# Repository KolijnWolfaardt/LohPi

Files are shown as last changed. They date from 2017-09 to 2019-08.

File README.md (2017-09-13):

# LohPi
A Lora Hat for Raspberry Pi

The PCB uses a [Semtech SX1301](http://www.semtech.com/images/datasheet/sx1301.pdf) to implement a full gateway for a LoRaWan connection. It is intended to plug into a Raspberri Pi 3 which manages the packet forwarding. 

# RF Frontend
The RF frontend is responsible for mixing down the signal, sampling it as IQ samples, and sending it to the SX1301 IC. For this two [SX1257](http://www.semtech.com/images/datasheet/sx1257.pdf) ICs are used. The schematic of the RF frontend is adapted from [Microchip's Documentation](http://ww1.microchip.com/downloads/en/DeviceDoc/40001827A.pdf).

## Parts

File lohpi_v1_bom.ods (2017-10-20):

Reference | Quantity | Value | Footprint | Datasheet | Voltage | I | Manufacturer | Manufacturer Code | Manufacturer Link | Supplier 1 | Supplier 1 Code | Supplier 1 Link | Supplier 2 | Supplier 2 Code | Supplier 2 Link
C1 C8 | 2 | 10uF | Capacitors_SMD:C_0603 |  | 25v |  | Taiuo Yuden | TMK107BBJ106MA-T |  | Mouser | 963-TMK107BBJ106MA-T | link (http://www.mouser.co.za/ProductDetail/Taiyo-Yuden/TMK107BBJ106MA-T/)
C10 C11 C12 C2 C37 C5 C9 | 7 | 4.7uF | Capacitors_SMD:C_0603 |  |  |  | Taiuo Yuden | JMK107BB7475KA-T |  | Mouser | 963-JMK107BB7475KA-T | link (http://www.mouser.co.za/ProductDetail/Taiyo-Yuden/JMK107BB7475KA-T/)
C13 C43 C44 C6 C78 C83 | 6 | 10nF | Capacitors_SMD:C_0402_NoSilk |  |  |  | Taiuo Yuden | TMK105B7103KVHF |  | Mouser | 963-TMK105B7103KVHF | link (http://www.mouser.co.za/ProductDetail/Taiyo-Yuden/TMK105B7103KVHF/)
C14 C15 C16 C17 C24 C30 C7 C84 C85 C86 C87 C89 C90 C91 | 14 | 1.0uF | Capacitors_SMD:C_0603 |  |  |  | Taiuo Yuden | GMK107AB7105MAHT |  | Mouser | 963-GMK107AB7105MAHT | link (http://www.mouser.co.za/ProductDetail/Taiyo-Yuden/GMK107AB7105MAHT/)
C18 C19 C20 C21 C22 C23 C53 C54 C56 C58 C61 C62 C65 C68 C69 C70 C71 C73 C75 C76 C77 | 21 | 56pF | Capacitors_SMD:C_0402_NoSilk |  |  |  | Vishay | VJ0402D560JXAAJ |  | Mouser | 77-VJ0402D560JXAAJ | link (http://www.mouser.co.za/search/ProductDetail.aspx?R=VJ0402D560JXAAJ)
 | 0 | 56pF | Capacitors_SMD:C_0402_NoSilk |  |  |  | Taiuo Yuden | UMK105CG560JV-F |  | Mouser | 963-UMK105CG560JV-F | link (http://www.mouser.co.za/ProductDetail/Taiyo-Yuden/UMK105CG560JV-F/)
C25 C26 C27 C28 C29 C3 C31 C32 C33 | 9 | 100nF | Capacitors_SMD:C_0603 |  |  |  | Taiuo Yuden | TMK107BJ104KA-T |  | Mouser | 963-TMK107BJ104KA-T | link (http://www.mouser.co.za/ProductDetail/Taiyo-Yuden/TMK107BJ104KA-T/)
C34 C35 C45 C47 C49 C50 | 6 | 1uF | Capacitors_SMD:C_0402_NoSilk |  |  |  | Taiuo Yuden | TMK105AC6105KV-F |  | Mouser | 963-TMK105AC6105KV-F | link (http://www.mouser.co.za/ProductDetail/Taiyo-Yuden/TMK105AC6105KV-F/)
C36 C39 C40 C41 C42 C46 C48 C63 C64 C82 C88 | 11 | 100nF | Capacitors_SMD:C_0402_NoSilk |  | 10v |  | Taiuo Yuden | LMK105B7104KV-F |  | Mouser | 963-LMK105B7104KV-F | link (http://www.mouser.co.za/ProductDetail/Taiyo-Yuden/LMK105B7104KV-F/)
C38 C4 C79 C80 | 4 | 1nF | Capacitors_SMD:C_0603 |  |  |  | Taiuo Yuden | HMK107B7102KA-T |  | Mouser | 963-HMK107B7102KA-T | link (http://www.mouser.co.za/ProductDetail/Taiyo-Yuden/HMK107B7102KA-T/)
C51 C52 C57 C60 C72 | 5 | DNP | Capacitors_SMD:C_0402_NoSilk
C55 C81 | 2 | 1.5pF | Capacitors_SMD:C_0402_NoSilk |  |  |  | Vishay | VJ0402D1R5BXCAJ |  | Mouser | 77-VJ0402D1R5BXCAJ | link (http://www.mouser.co.za/ProductDetail/Vishay-Vitramon/VJ0402D1R5BXCAJ/)
C59 C66 C67 | 3 | 2.2uF | Capacitors_SMD:C_0402_NoSilk |  |  |  | Taiuo Yuden | TMK105CBJ225MV-F |  | Mouser | 963-TMK105CBJ225MV-F | link (http://www.mouser.co.za/ProductDetail/Taiyo-Yuden/TMK105CBJ225MV-F/)
C74 | 1 | 5.6pF | Capacitors_SMD:C_0402_NoSilk |  |  |  | Vishay | VJ0402D5R6BXCAJ |  | Mouser | 77-VJ0402D5R6BXCAJ | link (http://www.mouser.co.za/ProductDetail/Vishay-Vitramon/VJ0402D5R6BXCAJ/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)
D1 D2 D3 D4 | 4 | LED | LEDs:LED_0603 |  |  |  | Broadcom | HSMR-C191-S0000 |  | Mouser | 630-HSMR-C191-S0000 | link (http://www.mouser.co.za/ProductDetail/Broadcom-Avago/HSMR-C191-S0000/)
J1 | 1 | CONN_01X02 | Pin_Headers:Pin_Header_Straight_1x02_Pitch2.54mm
J10 J11 J12 J13 | 4 | CONN_01X01 | rpi_mounting_hole:rpi_mounting_hole
J2 J3 J4 J5 J6 | 5 | CONN_01X01 | Pin_Headers:Pin_Header_Straight_1x01_Pitch2.54mm
J7 | 1 | UFL | hirose:u.fl | Datasheet (http://www.mouser.com/ds/2/238/conufl001-smd-1130574.pdf) |  |  | Linx Technologies | CONUFL001-SMD |  | Mouser | 712-CONUFL001-SMD | link (http://www.mouser.co.za/ProductDetail/Linx-Technologies/CONUFL001-SMD/)
J8 | 1 | raspberry_pi_3_header | Socket_Strips:Socket_Strip_Straight_2x20_Pitch2.54mm |  |  |  | Amphenol | 87606-310LF |  | Mouser | 649-87606-310LF | link (http://www.mouser.co.za/ProductDetail/Amphenol-FCI/87606-310LF/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)
J9 | 1 | CONN_01X02 | Connectors:SMA_THT_Jack_Straight |  |  |  | Linx Technologies | CONREVSMA002-G |  | Mouser | 712-CONREVSMA002-G | link (http://www.mouser.co.za/ProductDetail/Linx-Technologies/CONREVSMA002-G/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)
L1 | 1 | 3.3uH |  |  |  | 1A | muRata | 84332C |  | Mouser | 580-84332C | link (http://www.mouser.co.za/ProductDetail/Murata-Power-Solutions/84332C/)
L10 L11 L12 L13 L9 | 5 | 2.2uH | Inductors_SMD:L_0805 |  |  |  | muRata | DFE201210U-2R2M=P2 |  | Mouser | 81-DFE201210U-2R2MP2 | link (http://www.mouser.co.za/ProductDetail/Murata-Electronics/DFE201210U-2R2M=P2/)
L14 | 1 | 27nH | Inductors_SMD:L_0402 |  |  |  | muRata | LQP15MN27NG02D |  | Mouser | 81-LQP15MN27NG02D | link (http://www.mouser.co.za/ProductDetail/Murata-Electronics/LQP15MN27NG02D/)
L2 L3 | 2 | 1.5nH | Inductors_SMD:L_0402 |  |  |  | muRata | LQG15HN1N5C02D |  | Mouser | 81-LQG15HN1N5C02D | link (http://www.mouser.co.za/ProductDetail/Murata-Electronics/LQG15HN1N5C02D/)
L4 | 1 | 8.2nH | Inductors_SMD:L_0402 |  |  |  | muRata | LQG15HS8N2J02D |  | Mouser | 81-LQG15HS8N2J02D | link (http://www.mouser.co.za/ProductDetail/Murata-Electronics/LQG15HS8N2J02D/)
L5 | 1 | 100nH | Inductors_SMD:L_0402 |  |  |  | Coilcraft | 0402HPH-R10XGLW |  | Mouser | 994-0402HPH-R10XGLW | link (http://www.mouser.co.za/ProductDetail/Coilcraft/0402HPH-R10XGLW/)
L6 | 1 | 6.8nH | Inductors_SMD:L_0402 |  |  |  | muRata | LQP15MN6N8B02D |  | Mouser | 81-LQP15MN6N8B02D | link (http://www.mouser.co.za/ProductDetail/Murata-Electronics/LQP15MN6N8B02D/)
L7 | 1 | 18nH | Inductors_SMD:L_0402 |  |  |  | muRata | LQG15HN18NH02D |  | Mouser | 81-LQG15HN18NH02D | link (http://www.mouser.co.za/ProductDetail/Murata-Electronics/LQG15HN18NH02D/)
L8 | 1 | 2.7nH | Inductors_SMD:L_0402 |  |  |  | muRata | LQG15HN2N7C02D |  | Mouser | 81-LQG15HN2N7C02D | link (http://www.mouser.co.za/ProductDetail/Murata-Electronics/LQG15HN2N7C02D/)
Q1 | 1 | Q_PMOS_GSD | TO_SOT_Packages_SMD:SOT-23 |  |  |  | NXP | NXP BSS84
R1 R52 | 2 | 10 | Resistors_SMD:R_0402_NoSilk |  |  |  | Yageo | RC0402FR-0710RL |  | Mouser | 603-RC0402FR-0710RL | link (http://www.mouser.co.za/ProductDetail/Yageo/RC0402FR-0710RL/?qs=sGAEpiMZZMtlubZbdhIBIOcXbDHk16D4KZUsaU0VQDU%3D)
R2 R8 | 2 | 24.9k | Resistors_SMD:R_0603 |  |  |  | Yageo | RC0603FR-0724K9L |  | Mouser | 603-RC0603FR-0724K9L | link (http://www.mouser.co.za/ProductDetail/Yageo/RC0603FR-0724K9L/)
R22 R23 R26 R28 | 4 | 330 | Resistors_SMD:R_0603 |  |  |  | Yageo | RC0603JR-07330RL |  | Mouser | 603-RC0603JR-07330RL | link (http://www.mouser.co.za/ProductDetail/Yageo/RC0603JR-07330RL/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)
R24 R3 | 2 | 10k | Resistors_SMD:R_0603 |  |  |  | Yageo | RC0603FR-0710KL |  | Mouser | 603-RC0603FR-0710KL | link (http://www.mouser.co.za/ProductDetail/Yageo/RC0603FR-0710KL/)
R13 R14 R15 R21 R25 R27 R29 R30 R31 R32 R33 R34 R35 R51 R53 R54 R55 | 17 | 100 | Resistors_SMD:R_0603 |  |  |  | Yageo | RC0603FR-07100RL |  | Mouser | 603-RC0603FR-07100RL | link (http://www.mouser.co.za/ProductDetail/Yageo/RC0603FR-07100RL/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)
R37 R38 | 2 | 0 | Resistors_SMD:R_0402_NoSilk |  |  |  | Yageo | RC0402JR-070RL |  | Mouser | 603-RC0402JR-070RL | link (http://www.mouser.co.za/ProductDetail/Yageo/RC0402JR-070RL/?qs=sGAEpiMZZMtlubZbdhIBIJ0YzvSJmY5pgJvRKXcvvJ8%3D)
R39 R41 | 2 | 150 | Resistors_SMD:R_0402_NoSilk |  |  |  | Yageo | RC0402FR-07150RL |  | Mouser | 603-RC0402FR-07150RL | link (http://www.mouser.co.za/ProductDetail/Yageo/RC0402FR-07150RL/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)
R10 R11 R12 R4 R6 R9 | 6 | 0 | Resistors_SMD:R_0603 |  |  |  |  | RC0603JR-070RL |  | Mouser | 603-RC0603JR-070RL | link (http://www.mouser.co.za/ProductDetail/Yageo/RC0603JR-070RL/)
R40 R46 | 2 | 36.5 | Resistors_SMD:R_0402_NoSilk |  |  |  | Yageo | RC0402FR-0736R5L |  | Mouser | 603-RC0402FR-0736R5L | link (http://www.mouser.co.za/ProductDetail/Yageo/RC0402FR-0736R5L/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)
R43 | 1 | 500 | Resistors_SMD:R_0402_NoSilk |  |  |  | Yageo | RC0402FR-07499RL |  | Mouser | 603-RC0402FR-07499RL | link (http://www.mouser.co.za/ProductDetail/Yageo/RC0402FR-07499RL/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)
R44 | 1 | 49.9 | Resistors_SMD:R_0402_NoSilk |  |  |  | Yageo | RC0402FR-0749R9L |  | Mouser | 603-RC0402FR-0749R9L | link (http://www.mouser.co.za/ProductDetail/Yageo/RC0402FR-0749R9L/)
R42 R45 | 2 | DNP | Resistors_SMD:R_0402_NoSilk
R47 | 1 | 3.9 | Resistors_SMD:R_0402_NoSilk |  |  |  | Yageo | RC0402FR-073R9L |  | Mouser | 603-RC0402FR-073R9L | link (http://www.mouser.co.za/ProductDetail/Yageo/RC0402FR-073R9L/?qs=sGAEpiMZZMtlubZbdhIBIM2VF1SoZtZzUiW6eNU3mOY%3D)
R48 R49 R56 R57 R58 R59 R60 R61 R62 R63 R64 | 11 | 100 | Resistors_SMD:R_0402_NoSilk |  |  |  | Yageo | RC0402FR-13100RL |  | Mouser | 603-RC0402FR-13100RL | link (http://www.mouser.co.za/ProductDetail/Yageo/RC0402FR-13100RL/)
R16 R17 R18 R19 R20 R36 R5 | 7 | DNP | Resistors_SMD:R_0603
R50 | 1 | 30 | Resistors_SMD:R_0402_NoSilk |  |  |  | Yageo | RC0402FR-0730RL |  | Mouser | 603-RC0402FR-0730RL | link (http://www.mouser.co.za/ProductDetail/Yageo/RC0402FR-0730RL/)
R7 | 1 | 30.9k | Resistors_SMD:R_0603 |  |  |  | Yageo | RC0402FR-0730K9L |  | Mouser | 603-RC0402FR-0730K9L | link (http://www.mouser.co.za/ProductDetail/Yageo/RC0402FR-0730K9L/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)
U10 | 1 | Anaren_B0430J50100AHF | anaren_balun:anaren_balun | Datasheet (http://www.mouser.com/ds/2/21/B0430J50100AHF_DataSheet_RevA-15384.pdf) |  |  | Anaren | B0430J50100AHF |  | Mouser | 620-B0430J50100AHF | link (http://www.mouser.co.za/ProductDetail/Anaren/B0430J50100AHF/?qs=61pwXRo0i5hJ5yOyYTWnSA==) | Digikey | 1173-1052-1-ND | link (https://www.digikey.com/product-detail/en/anaren/B0430J50100AHF/1173-1052-1-ND/3069250)
U11 U12 U15 U17 | 4 | MurataSF2314E | murata_saw_filter:murata_saw_filter | Datasheet (http://www.mouser.com/ds/2/281/sf2314e-1100145.pdf) |  |  | muRata | SF2314E |  | Mouser | 81-SF2314E | link (http://www.mouser.co.za/ProductDetail/Murata-Electronics/SF2314E/)
U13 | 1 | SPF5043Z | quorvo:quorvo_spf5043z | Datasheet (http://www.mouser.com/ds/2/412/pf5043z_product_data_sheet-781790.pdf) |  |  | Qorvo | SPF5043Z |  | Mouser | 772-SPF5043Z | link (http://www.mouser.co.za/ProductDetail/Qorvo/SPF5043Z/)
U14 | 1 | RFPA0133TR7 | Housings_DFN_QFN:QFN-16-1EP_3x3mm_Pitch0.5mm | Datasheet (http://www.qorvo.com/products/d/da000936) |  |  | Qorvo | RFPA0133TR7 |  | Mouser | 772-RFPA0133 | Link (http://www.mouser.co.za/ProductDetail/RFMD-Qorvo/RFPA0133TR7/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)
U16 | 1 | RFSW1012 | quorvo:rfsw1012DS | Datasheet (http://www.mouser.com/ds/2/412/RFSW1012%20Data%20Sheet-1112876.pdf) |  |  | Qorvo | RFSW1012TR7 |  | Mouser | 772-RFSW1012 | link (http://www.mouser.co.za/ProductDetail/RFMD-Qorvo/RFSW1012TR7/)
U18 | 1 | MAX-M8 | max_8:MAX-M8 | Datasheet (https://www.u-blox.com/sites/default/files/MAX-8-M8-FW3_HardwareIntegrationManual_%28UBX-15030059%29.pdf) |  |  | U-blox | MAX-M8Q |  | Digikey | 672-1003-1-ND | link (https://www.digikey.com/product-detail/en/u-blox-america-inc/MAX-M8Q-0/672-1003-1-ND/6150666) | RF Design | MAX-M8Q-0-000-1 | link (http://rf-design.co.za/product/u-blox-m8-rom-based-gnss-module-2-7-3-6v/)
U2 | 1 | MCP1612 | Housings_SSOP:MSOP-8_3x3mm_Pitch0.65mm | Datasheet (http://ww1.microchip.com/downloads/en/DeviceDoc/21921C.pdf) |  |  | Microchip | MCP1612T-ADJI/MS |  | Mouser | 579-MCP1612T-ADJI/MS | link (http://www.mouser.co.za/ProductDetail/Microchip-Technology/MCP1612T-ADJI-MS/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)
U1 U3 | 2 | MCP1726-3302E/SN | Housings_SOIC:SOIC-8_3.9x4.9mm_Pitch1.27mm | Datasheet (http://ww1.microchip.com/downloads/en/DeviceDoc/20001936D.pdf) |  |  | Microchip | MCP1726-3302E/SN |  | Mouser | 579-MCP1726-3302E/SN | link (http://www.mouser.co.za/ProductDetail/Microchip-Technology/MCP1726-3302E-SN/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)
U4 U5 U6 | 3 | MCP1824 | TO_SOT_Packages_SMD:SOT-23-5 | Datasheet (http://ww1.microchip.com/downloads/en/DeviceDoc/22070a.pdf) |  |  | Microchip | MCP1824T-3302E/OT |  | Mouser | 579-MCP1824T-3302EOT | link (http://www.mouser.co.za/ProductDetail/Microchip-Technology/MCP1824T-3302E-OT/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)
U7 | 1 | SX1301 | Housings_DFN_QFN:QFN-64-1EP_9x9mm_Pitch0.5mm | Datasheet (http://www.semtech.com/images/datasheet/sx1301.pdf) |  |  | Semtech | SX1301 | link (http://www.semtech.com/wireless-rf/rf-transceivers/sx1301/) | Digikey | SX1301IMLTRCCT-ND | link (https://www.digikey.com/product-detail/en/semtech-corporation/SX1301IMLTRC/SX1301IMLTRCCT-ND/7386313)
U8 U9 | 2 | SX1257 | Housings_DFN_QFN:QFN-32-1EP_5x5mm_Pitch0.5mm | Datasheet (http://www.semtech.com/images/datasheet/sx1257.pdf) |  |  | Semtech | SX1257 | link (http://www.semtech.com/wireless-rf/rf-transceivers/sx1257/) | Digikey | SX1257IWLTRTCT-ND | link (https://www.digikey.com/product-detail/en/semtech-corporation/SX1257IWLTRT/SX1257IWLTRTCT-ND/5226785)
X1 | 1 | ABRACON-OSC | crystal_osc_1:ABRACON-OSC | Datasheet (http://www.mouser.com/ds/2/3/ASEMB-7474.pdf) |  |  | Abracon | ASEMB-133.333MHZ-LY-T |  |  | 815-ASEMB-133.3-LY-T | link (http://www.mouser.co.za/ProductDetail/ABRACON/ASEMB-133333MHZ-LY-T/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)
X2 | 1 | ABRACON-OSC | crystal_osc_1:ABRACON-OSC | Datasheet (http://www.mouser.com/ds/2/3/ASEMB-7474.pdf) |  |  | Abracon | ASEMB-32.000MHZ-LY-T |  |  | 815-ASEMB-32-LY-T | link (http://www.mouser.co.za/ProductDetail/ABRACON/ASEMB-32000MHZ-LY-T/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)

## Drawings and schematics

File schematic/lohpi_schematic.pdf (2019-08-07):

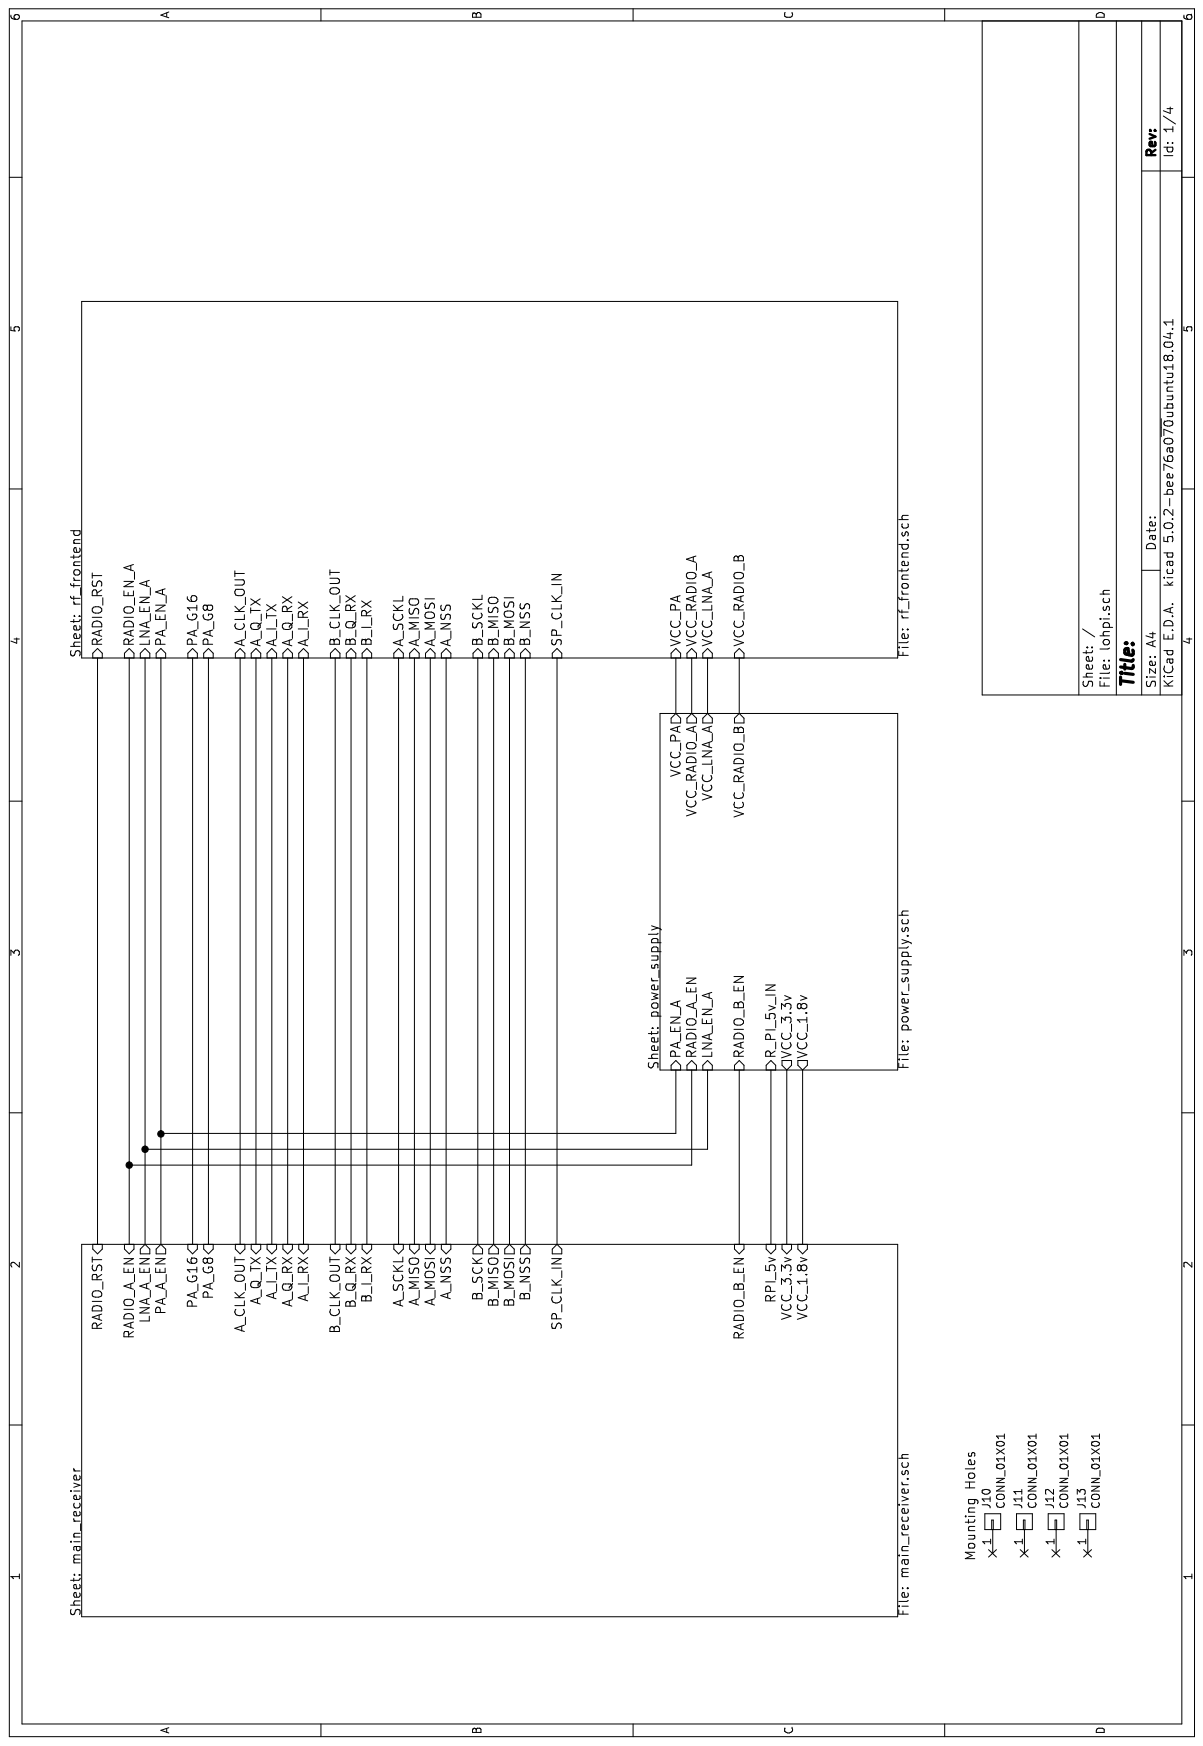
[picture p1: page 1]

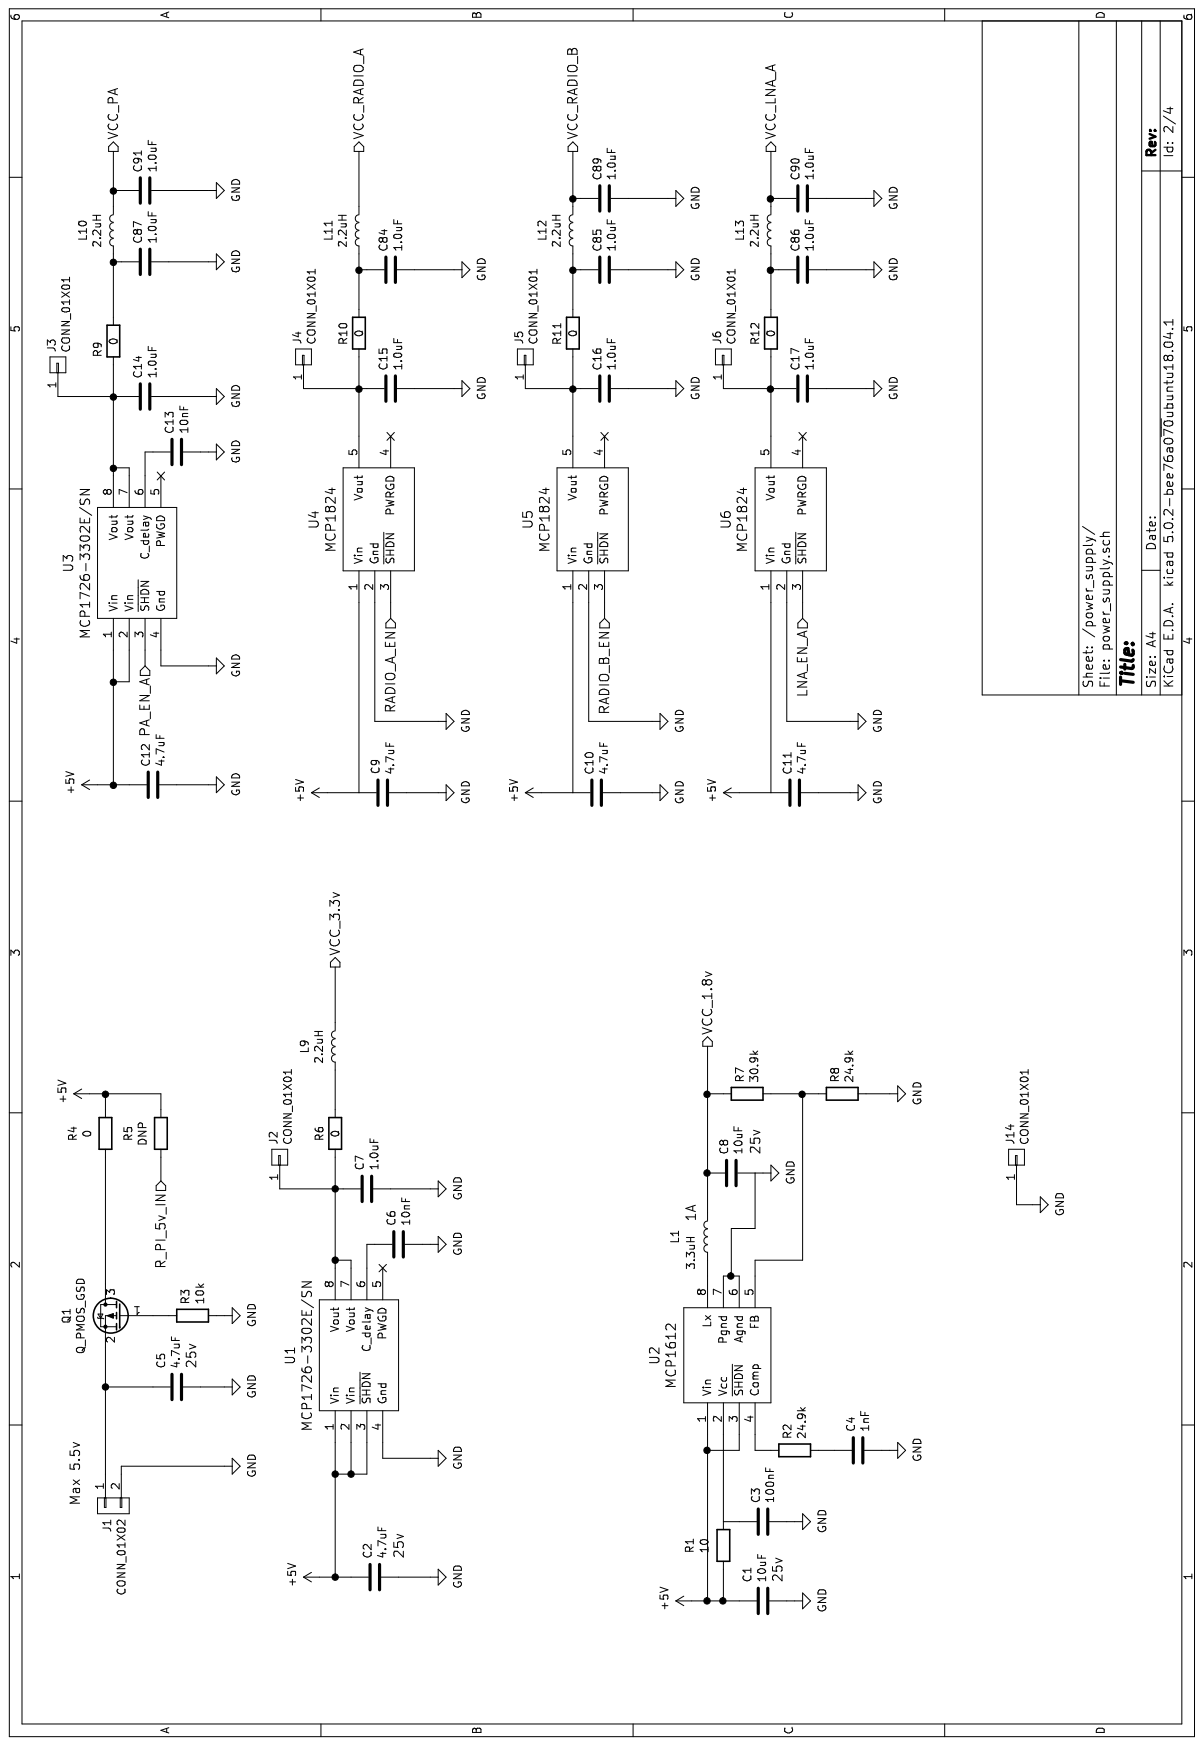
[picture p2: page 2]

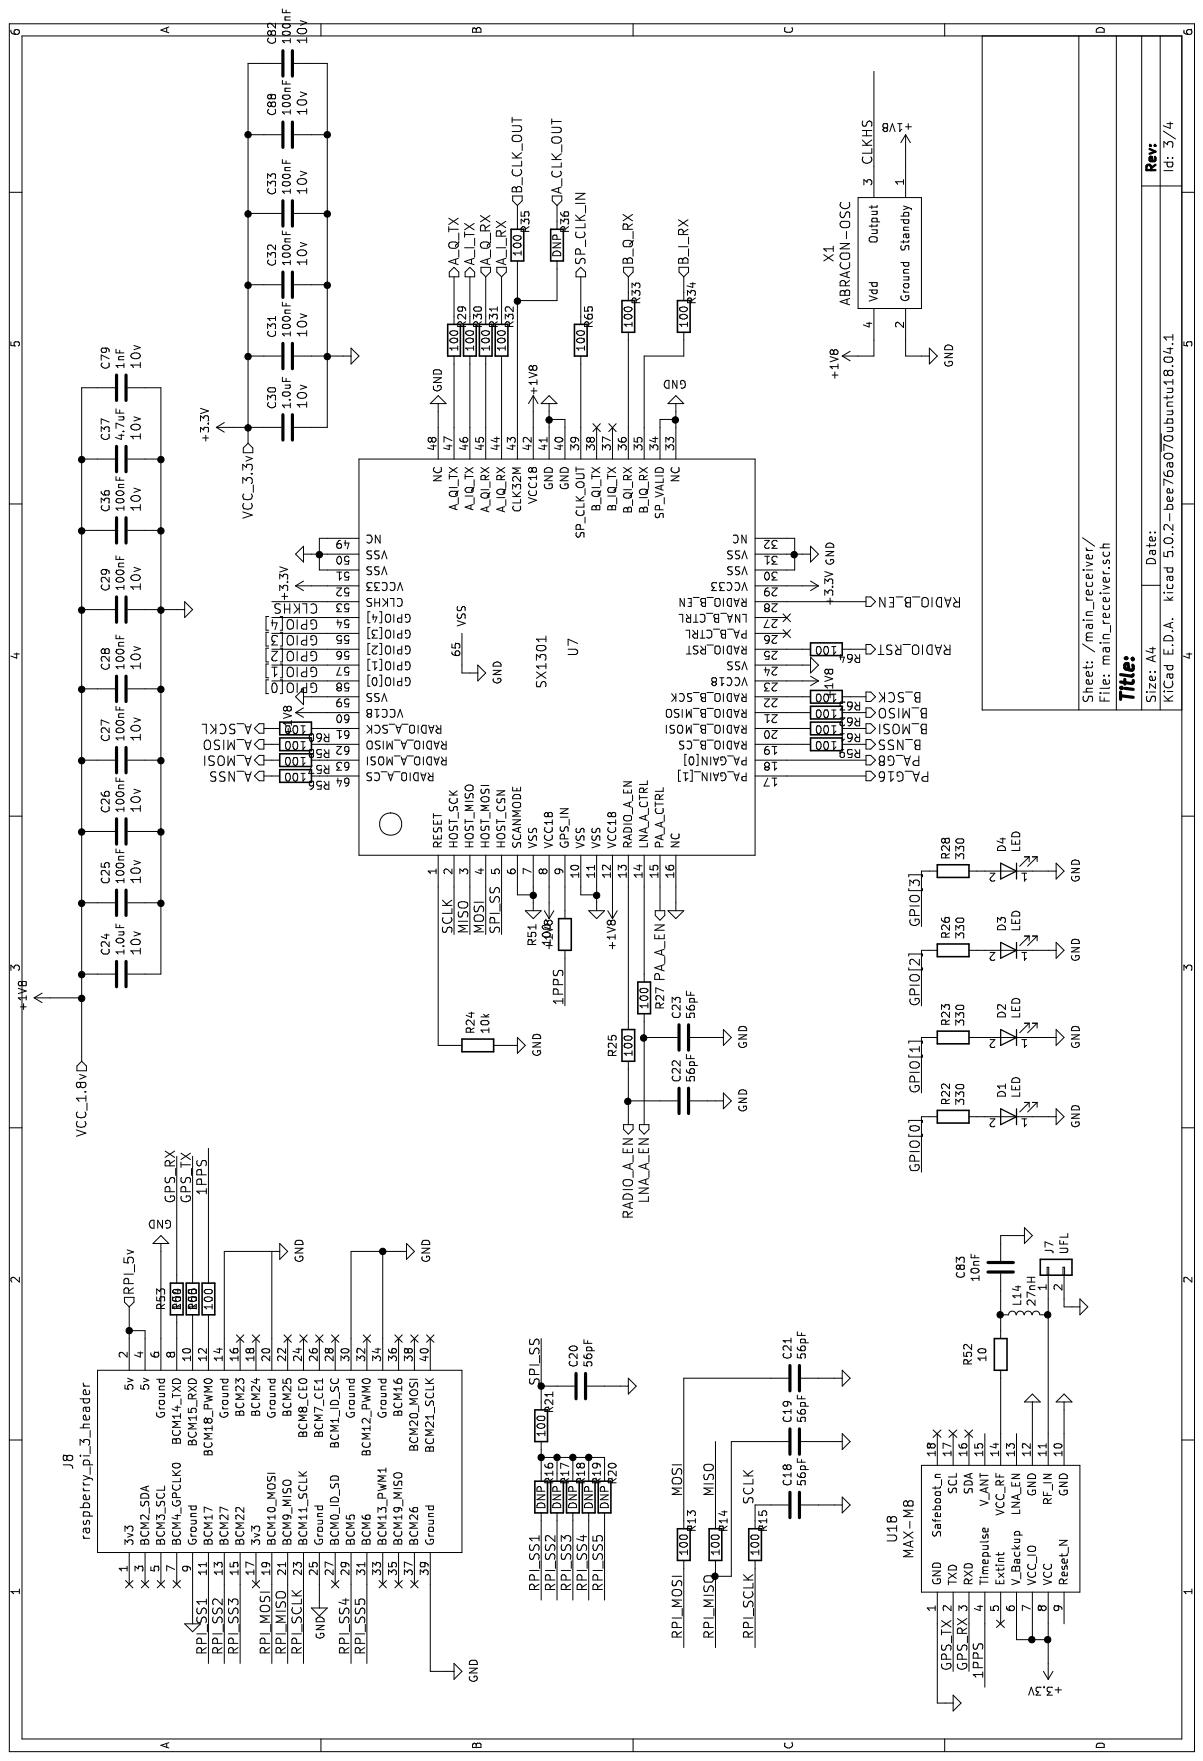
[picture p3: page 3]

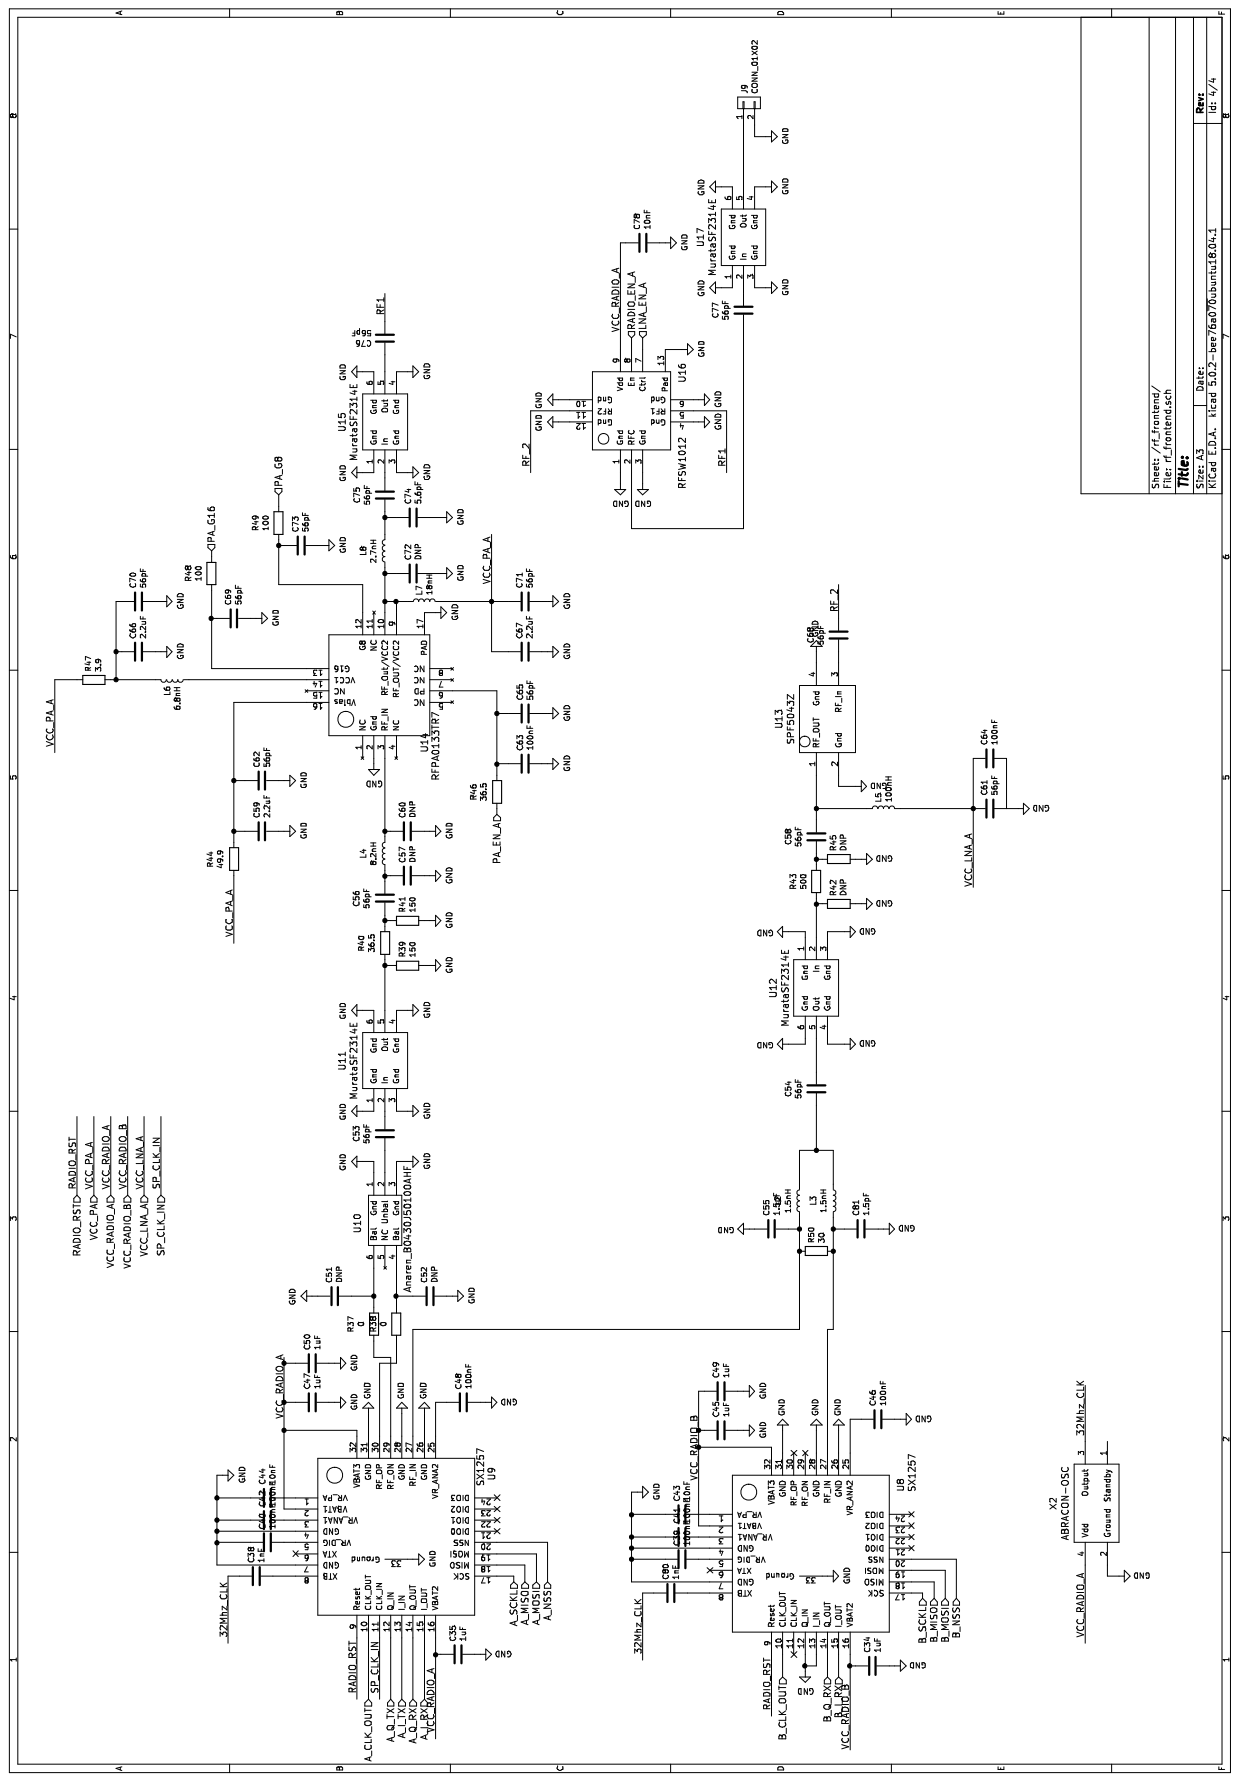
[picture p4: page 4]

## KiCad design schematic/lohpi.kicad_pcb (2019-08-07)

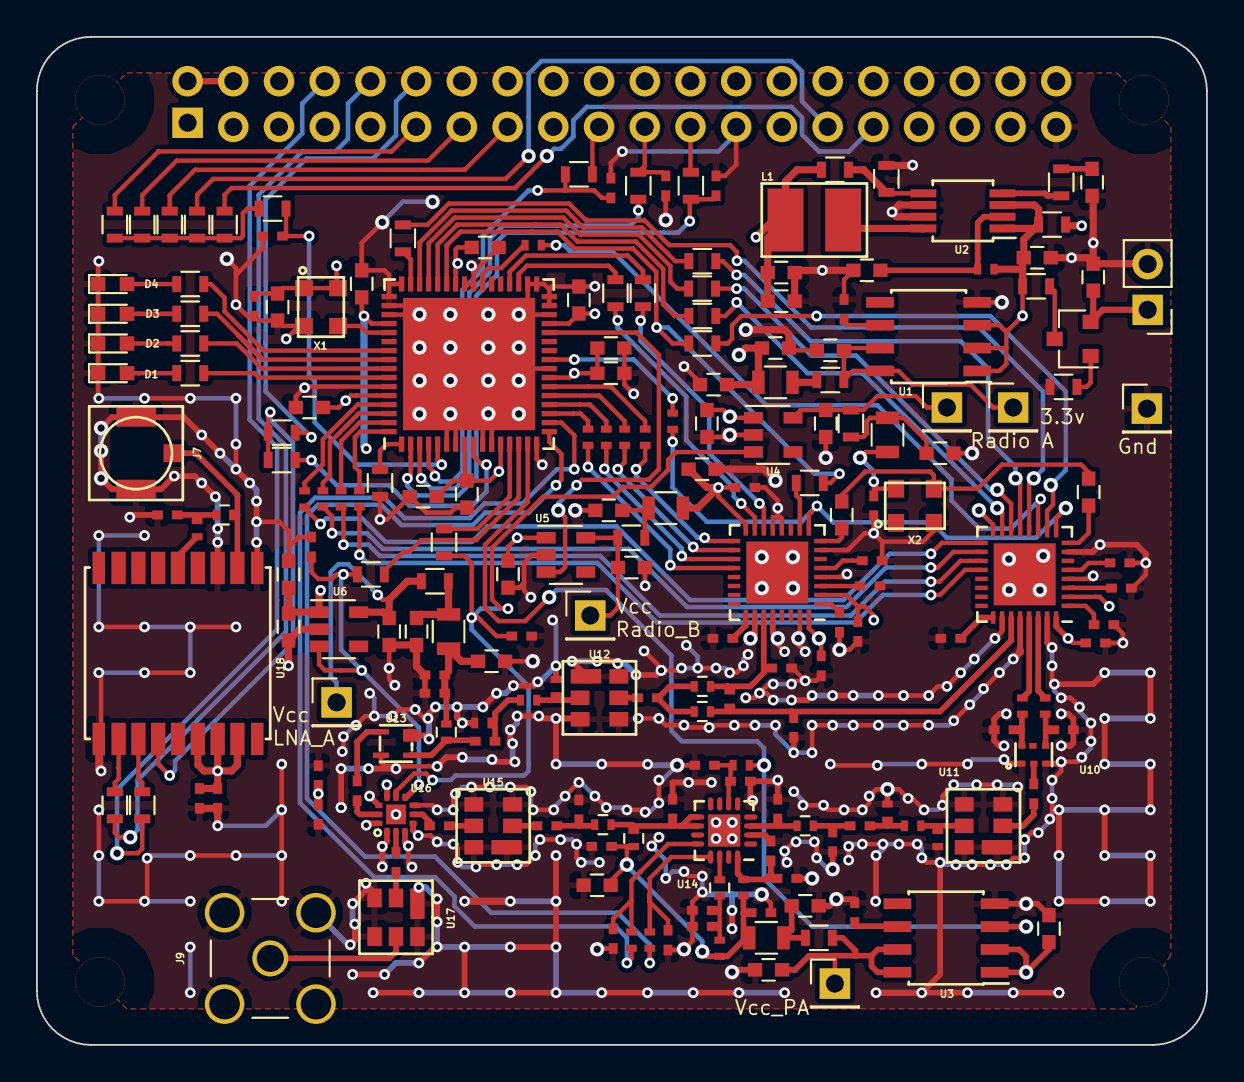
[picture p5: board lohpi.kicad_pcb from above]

Board: 4 copper layers, 65.0 x 56.0 mm, 209 parts (1 on the bottom side), 149 nets.

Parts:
C1, C8: 10uF; C_0603
C2, C5, C9, C10, C11, C12, C37: 4.7uF; C_0603
C3, C25, C26, C27, C28, C29, C31, C32, C33: 100nF; C_0603
C4, C38, C79, C80: 1nF; C_0603
C6, C13, C43, C44, C78, C83: 10nF; C_0402_NoSilk
C7, C14, C15, C16, C17, C24, C30, C84, C85, C86, C87, C89, C90, C91: 1.0uF; C_0603
C18, C19, C20, C21, C22, C23, C53, C54, C56, C58, C61, C62, C65, C68, C69, C70, C71, C73, C75, C76, C77: 56pF; C_0402_NoSilk
C34, C35, C45, C47, C49, C50: 1uF; C_0402_NoSilk
C36, C39, C40, C41, C42, C46, C48, C63, C64, C82, C88: 100nF; C_0402_NoSilk
C51, C52, C57, C60, C72: DNP; C_0402_NoSilk
C55, C81: 1.5pF; C_0402_NoSilk
C59, C66, C67: 2.2uF; C_0402_NoSilk
C74: 5.6pF; C_0402_NoSilk
D1, D2, D3, D4: LED; LED_0603
J1: CONN_01X02; Pin_Header_Straight_1x02_Pitch2.54mm
J2, J3, J4, J5, J6, J14: CONN_01X01; Pin_Header_Straight_1x01_Pitch2.54mm
J7: UFL; u.fl
J8: raspberry_pi_3_header; Socket_Strip_Straight_2x20_Pitch2.54mm
J9: CONN_01X02; SMA_THT_Jack_Straight
J10, J11, J12, J13: CONN_01X01; rpi_mounting_hole
L1: 3.3uH; 84332C
L2, L3: 1.5nH; L_0402
L4: 8.2nH; L_0402
L5: 100nH; L_0402
L6: 6.8nH; L_0402
L7: 18nH; L_0402
L8: 2.7nH; L_0402
L9, L10, L11, L12, L13: 2.2uH; L_0805
L14: 27nH; L_0402
Q1: Q_PMOS_GSD; SOT-23
R1, R52: 10; R_0402_NoSilk
R2, R8: 24.9k; R_0603
R3, R24: 10k; R_0603
R4, R6, R9, R10, R11, R12: 0; R_0603
R5, R16, R17, R18, R19, R20, R36: DNP; R_0603
R7: 30.9k; R_0603
R13, R14, R15, R21, R25, R27, R29, R30, R31, R32, R33, R34, R35, R51, R53, R54, R55: 100; R_0603
R22, R23, R26, R28: 330; R_0603
R37, R38: 0; R_0402_NoSilk
R39, R41: 150; R_0402_NoSilk
R40, R46: 36.5; R_0402_NoSilk
R42, R45: DNP; R_0402_NoSilk
R43: 500; R_0402_NoSilk
R44: 49.9; R_0402_NoSilk
R47: 3.9; R_0402_NoSilk
R48, R49, R56, R57, R58, R59, R60, R61, R62, R63, R64, R65: 100; R_0402_NoSilk
R50: 30; R_0402_NoSilk
U1, U3: MCP1726-3302E/SN; SOIC-8_3.9x4.9mm_Pitch1.27mm
U2: MCP1612; MSOP-8_3x3mm_Pitch0.65mm
U4, U5, U6: MCP1824; SOT-23-5
U7: SX1301; QFN-64-1EP_9x9mm_Pitch0.5mm
U8, U9: SX1257; QFN-32-1EP_5x5mm_Pitch0.5mm
U10: Anaren_B0430J50100AHF; anaren_balun
U11, U12, U15, U17: MurataSF2314E; murata_saw_filter
U13: SPF5043Z; quorvo_spf5043z
U14: RFPA0133TR7; QFN-16-1EP_3x3mm_Pitch0.5mm
U16: RFSW1012; rfsw1012DS
U18: MAX-M8
X1, X2: ABRACON-OSC

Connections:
+1V8: C8.1, C24.1, C25.1, C26.1, C27.1, C28.1, C29.1, C36.1, C37.1, C79.1, L1.2, R7.1, U7.8, U7.12, U7.23, U7.42, U7.60, X1.1, X1.4
+3V3: C30.1, C31.1, C32.1, C33.1, C82.1, C88.1, L9.2, U7.29, U7.52, U18.6, U18.7, U18.8
+5V: C1.1, C2.1, C9.1, C10.1, C11.1, C12.1, R1.1, R4.1, R5.1, U1.1, U1.2, U1.3, U2.1, U2.3, U3.1, U3.2, U4.1, U5.1, U6.1
/main_receiver/1PPS: R51.2, R55.1, U18.4
/main_receiver/A_CLK_OUT: R36.1, U9.10
/main_receiver/A_I_RX: R32.1, U9.15
/main_receiver/A_I_TX: R30.1, U9.13
/main_receiver/A_MISO: R58.2, U9.18
/main_receiver/A_MOSI: R57.2, U9.19
/main_receiver/A_NSS: R56.2, U9.20
/main_receiver/A_Q_RX: R31.1, U9.14
/main_receiver/A_Q_TX: R29.1, U9.12
/main_receiver/A_SCKL: R60.2, U9.17
/main_receiver/B_CLK_OUT: R35.1, U8.10
/main_receiver/B_I_RX: R34.1, U8.15
/main_receiver/B_MISO: R62.1, U8.18
/main_receiver/B_MOSI: R61.1, U8.19
/main_receiver/B_NSS: R59.1, U8.20
/main_receiver/B_Q_RX: R33.1, U8.14
/main_receiver/B_SCK: R63.1, U8.17
/main_receiver/CLKHS: U7.53, X1.3
/main_receiver/GPIO[0]: R22.1, U7.58
/main_receiver/GPIO[1]: R23.1, U7.57
/main_receiver/GPIO[2]: R26.1, U7.56
/main_receiver/GPIO[3]: R28.1, U7.55
/main_receiver/GPS_RX: R53.1, U18.3
/main_receiver/GPS_TX: R54.1, U18.2
/main_receiver/LNA_A_EN: C23.1, R27.2, U6.3, U16.7
/main_receiver/MISO: R14.1, U7.3
/main_receiver/MOSI: C21.1, R13.1, U7.4
/main_receiver/PA_A_EN: R46.1, U3.3, U7.15
/main_receiver/PA_G8: R49.1, U7.18
/main_receiver/PA_G16: R48.1, U7.17
/main_receiver/RADIO_A_EN: C22.1, R25.2, U4.3, U16.8
/main_receiver/RADIO_B_EN: U5.3, U7.28
/main_receiver/RADIO_RST: R64.1, U8.9, U9.9
/main_receiver/RPI_5v: J8.2, J8.4, R5.2
/main_receiver/RPI_MISO: C19.1, J8.21, R14.2
/main_receiver/RPI_MOSI: J8.19, R13.2
/main_receiver/RPI_SCLK: J8.23, R15.2
/main_receiver/RPI_SS1: J8.11, R16.2
/main_receiver/RPI_SS2: J8.13, R17.2
/main_receiver/RPI_SS3: J8.15, R18.2
/main_receiver/RPI_SS4: J8.29, R19.2
/main_receiver/RPI_SS5: J8.31, R20.2
/main_receiver/SCLK: C18.1, R15.1, U7.2
/main_receiver/SPI_SS: C20.1, R21.1, U7.5
/main_receiver/SP_CLK_IN: R65.1, U9.11
/power_supply/VCC_LNA_A: C61.2, C64.2, C90.1, L5.2, L13.2
/power_supply/VCC_PA: C67.2, C71.2, C91.1, L7.2, L10.2, R44.1, R47.2
/power_supply/VCC_RADIO_A: C35.1, C47.1, C50.1, C78.2, L11.2, U9.2, U9.16, U9.32, U16.9, X2.4
/power_supply/VCC_RADIO_B: C34.1, C45.1, C49.1, C89.1, L12.2, U8.2, U8.16, U8.32
/rf_frontend/32Mhz_CLK: C38.1, C80.1, X2.3
/rf_frontend/RF1: C76.2, U16.5
/rf_frontend/RF_2: C68.1, U16.11
GND: C1.2, C2.2, C3.2, C4.2, C5.2, C6.2, C7.2, C8.2, C9.2, C10.2, C11.2, C12.2, C13.2, C14.2, C15.2, C16.2, C17.2, C18.2, C19.2, C20.2, C21.2, C22.2, C23.2, C24.2, C25.2, C26.2, C27.2, C28.2, C29.2, C30.2, C31.2, C32.2, C33.2, C34.2, C35.2, C36.2, C37.2, C39.1, C40.1, C41.1, C42.1, C43.1, C44.1, C45.2, C46.2, C47.2, C48.2, C49.2, C50.2, C51.2, C52.1, C55.1, C57.2, C59.2, C60.2, C61.1, C62.2, C63.2, C64.1, C65.2, C66.1, C67.1, C69.1, C70.1, C71.1, C72.2, C73.1, C74.2, C78.1, C79.2, C81.2, C82.2, C83.1, C84.2, C85.2, C86.2, C87.2, C88.2, C89.2, C90.2, C91.2, D1.1, D2.1, D3.1, D4.1, J1.2, J7.2, J8.6, J8.9, J8.14, J8.20, J8.25, J8.30, J8.34, J8.39, J9.2, J14.1, R3.2, R8.2, R24.2, R39.2, R41.2, R42.1, R45.1, U1.4, U2.6, U2.7, U3.4, U4.2, U5.2, U6.2, U7.6, U7.7, U7.10, U7.11, U7.16, U7.24, U7.30, U7.31, U7.32, U7.33, U7.34, U7.40, U7.41, U7.48, U7.49, U7.50, U7.51, U7.59, U7.65, U8.4, U8.7, U8.12, U8.13, U8.26, U8.28, U8.31, U8.33, U9.4, U9.7, U9.26, U9.28, U9.31, U9.33, U10.1, U10.3, U11.1, U11.3, U11.4, U11.6, U12.1, U12.3, U12.4, U12.6, U13.2, U13.4, U14.2, U14.17, U15.1, U15.3, U15.4, U15.6, U16.1, U16.3, U16.4, U16.6, U16.10, U16.12, U16.13, U17.1, U17.3, U17.4, U17.6, U18.1, U18.10, U18.12, X1.2, X2.2
unnamed: C3.1, R1.2, U2.2
unnamed: C4.1, R2.2
unnamed: C5.1, J1.1, Q1.2
unnamed: C6.1, U1.6
unnamed: C7.1, J2.1, R6.2, U1.7, U1.8
unnamed: C13.1, U3.6
unnamed: C14.1, J3.1, R9.2, U3.7, U3.8
unnamed: C15.1, J4.1, R10.2, U4.5
unnamed: C16.1, J5.1, R11.2, U5.5
unnamed: C17.1, J6.1, R12.2, U6.5
unnamed: C38.2, U9.8
unnamed: C39.2, U8.5
unnamed: C40.2, U9.5
unnamed: C41.2, U8.3
unnamed: C42.2, U9.3
unnamed: C43.2, U8.1
unnamed: C44.2, U9.1
unnamed: C46.1, U8.25
unnamed: C48.1, U9.25
unnamed: C51.1, R37.1, U10.6
unnamed: C52.2, R38.1, U10.4
unnamed: C53.1, U10.2
unnamed: C53.2, U11.2
unnamed: C54.1, U12.5
unnamed: C54.2, L2.2, L3.1
unnamed: C55.2, L2.1, R50.1, U9.27
unnamed: C56.1, R40.2, R41.1
unnamed: C56.2, C57.1, L4.1
unnamed: C58.1, L5.1, U13.1
unnamed: C58.2, R43.1, R45.2
unnamed: C59.1, C62.1, R44.2, U14.16
unnamed: C60.1, L4.2, U14.3
unnamed: C63.1, C65.1, R46.2, U14.6
unnamed: C66.2, C70.2, L6.1, R47.1
unnamed: C68.2, U13.3
unnamed: C69.2, R48.2, U14.13
unnamed: C72.1, L7.1, L8.1, U14.9, U14.10
unnamed: C73.2, R49.2, U14.12
unnamed: C74.1, C75.2, L8.2
unnamed: C75.1, U15.2
unnamed: C76.1, U15.5
unnamed: C77.1, U17.2
unnamed: C77.2, U16.2
unnamed: C80.2, U8.8
unnamed: C81.1, L3.2, R50.2, U8.27
unnamed: C83.2, L14.1, R52.1
unnamed: C84.1, L11.1, R10.1
unnamed: C85.1, L12.1, R11.1
unnamed: C86.1, L13.1, R12.1
unnamed: C87.1, L10.1, R9.1
unnamed: D1.2, R22.2
unnamed: D2.2, R23.2
unnamed: D3.2, R26.2
unnamed: D4.2, R28.2
unnamed: J7.1, L14.2, U18.11
unnamed: J8.8, R53.2
unnamed: J8.10, R54.2
unnamed: J8.12, R55.2
unnamed: J9.1, U17.5
unnamed: L1.1, U2.8
unnamed: L6.2, U14.14
unnamed: L9.1, R6.1
unnamed: Q1.1, R3.1
unnamed: Q1.3, R4.2
unnamed: R2.1, U2.4
unnamed: R7.2, R8.1, U2.5
unnamed: R16.1, R17.1, R18.1, R19.1, R20.1, R21.2
unnamed: R24.1, U7.1
unnamed: R25.1, U7.13
unnamed: R27.1, U7.14
unnamed: R29.2, U7.47
unnamed: R30.2, U7.46
unnamed: R31.2, U7.45
unnamed: R32.2, U7.44
unnamed: R33.2, U7.36
unnamed: R34.2, U7.35
unnamed: R35.2, R36.2, U7.43
unnamed: R37.2, U9.29
unnamed: R38.2, U9.30
unnamed: R39.1, R40.1, U11.5
unnamed: R42.2, R43.2, U12.2
unnamed: R51.1, U7.9
unnamed: R52.2, U18.14
unnamed: R56.1, U7.64
unnamed: R57.1, U7.63
unnamed: R58.1, U7.62
unnamed: R59.2, U7.19
unnamed: R60.1, U7.61
unnamed: R61.2, U7.20
unnamed: R62.2, U7.21
unnamed: R63.2, U7.22
unnamed: R64.2, U7.25
unnamed: R65.2, U7.39

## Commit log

2017-09-09 First schematic commit. No GPS module yet.
    [_saved_rf_frontendsch.sch, lohpi.sch, main_receiver.sch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]
2017-09-10 Updates to schematic, components
    [lohpi.kicad_pcb, lohpi.sch, main_receiver.sch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]
2017-09-10 Adds footprint for crystal
    [main_receiver.sch, rf_frontend.sch]
2017-09-23 Schematic capture almost done. RF layout started.
    [lohpi.kicad_pcb, lohpi.sch, main_receiver.sch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]
2017-09-30 RF layout updated. Rest still needs work
    [lohpi.kicad_pcb, lohpi.sch, main_receiver.sch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]
2017-10-01 PCB layout finished, needs review
    [lohpi.kicad_pcb, main_receiver.sch, power_supply.sch]
2017-10-01 Adds via stitching, better ground infill.
    [lohpi.kicad_pcb]
2017-10-03 HF layout changed, GPS module added
    [lohpi.kicad_pcb, lohpi.sch, main_receiver.sch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]
2017-10-07 Layout approaching final version. BOM updated
    [lohpi.kicad_pcb, lohpi_bom_grouped.csv, lohpi_v1_bom.ods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]
2017-10-11 More updates to bom, added resistors to all communication lines
    [lohpi.kicad_pcb, lohpi_v1_bom.ods, main_receiver.sch]
2017-10-18 Add the rest of the passive components to bom
    [lohpi.kicad_pcb, lohpi_v1_bom.ods, power_supply.sch]
2017-10-20 Correct component for SMPS inductor, changed footprint
    [lohpi.kicad_pcb, lohpi.sch, lohpi_v1_bom.ods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]
2017-10-21 Moved all references to F.Fab, cleaned up silkscreen
    [lohpi.kicad_pcb, power_supply.sch]
2017-11-12 Version sent to fab
    [lohpi.kicad_pcb]
2019-08-07 Convert to Kicad 5, fix Front Fab layer
    [lohpi-2019-07-24-18-30-34.sch, lohpi-2019-08-07-21-38-35.sch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]
